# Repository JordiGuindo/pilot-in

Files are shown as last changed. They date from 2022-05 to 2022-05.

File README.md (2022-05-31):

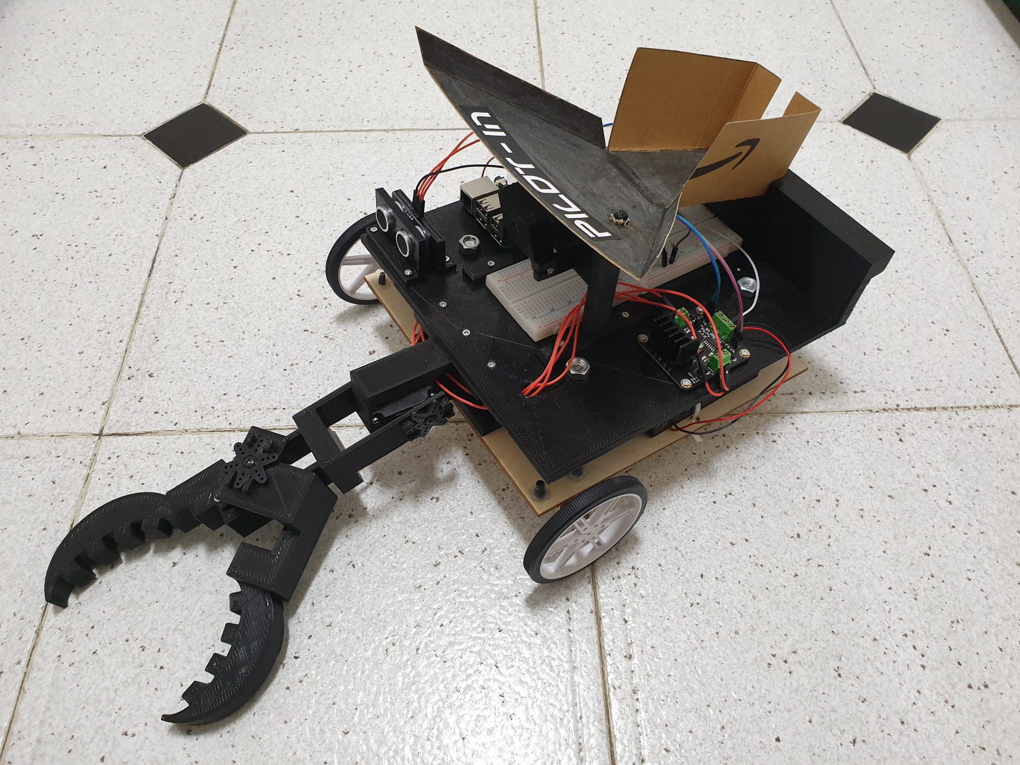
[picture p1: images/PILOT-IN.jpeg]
header pic


# PILOT-IN
This robot recognises ping-pong balls using computer vision and gets them with the help of an arm. It stores them in a removable case. 

# Table of Contents
   * [What is this?](#what-is-this)
   * [Requirements](#requirements)
   * [Amazing contributions](#amazing-contributions)
   * [Hardware](#hardware)
   * [Software](#software)
   	 * [Image capture](#image-capture)
   	 * [Distance sensor module](#distance-sensor-module)
   	 * [Ball detecion](#ball-detection)
	 * [Motion planner](#motion-planner)
   	 * [Wheel control](#wheel-control)
	 * [Arm control](#arm-control)
   * [Contribution](#contribution)
   * [Citing](#citing)
   * [Authors](#authors)
   * [Bibliography](#biblio)
# What is this?
This is our final project for the Robotics, Language and Planification (RLP) subject at the Universitat Autonoma de Barcelona (UAB). 
We presented PILOT-IN, a robot whose objective is to recognise ping-pong balls and pick them up. Here bellow, we explain how the robot was built and how we made it work correctly.
# Requirements
- Coding Requirements
	- [Python 3.10.x](https://www.python.org/)
	- [NumPy](https://numpy.org/)
	- [OpenCV](https://opencv.org/)
- Electronic components
	- Raspberry Pi 3B
	- Raspberry Pi Camera V2
	- Motor Dual controller H-Bridge v1.3
	- Standard servomotor 3001 HB (2)
	- HC-SR04 ultrasonic distance sensor
	- Wheels (2) and crazy wheel
	- Pololu micrometal motors 75:1 (2)
- 3D pieces
	- They are all [here](https://github.com/JordiGuindo/pilot-in/tree/main/3D)
# Amazing contributions
Our robot is aimed at professional ping pong athletes. It will be used in the specific situation where the athlete needs to train a certain aspect of the game for which it is necessary to use several balls. Our robot allows the athlete to train without the help of anyone to collect the balls, which improves the efficiency of training and contributes to the improvement of results in the competition.  
The robot is able to make individual workouts much more efficient, without the need to have people picking up balls.
It can also be used if you are not a professional athlete, but the full potential of the robot will not be exploited, as it will not be used as often. However, it can help to prevent back pain, as it will not be necessary to bend down to look for all the balls. It can be used in cases of therapy, if there has been an injury to the arm. If rehabilitation involves throwing a ball, it may be helpful to the patient.  
On the other hand, our robot is scalable. The design can be adapted for different sports, and different capacities (maximum number of balls collected). Depending on the sport played, the different components of the robot can be changed to collect the balls based on what the playing field is like, what the size of the balls is and what the optimal number of balls to be loaded is.  

# Hardware
The following picture shows how all the electronic components are connected. 
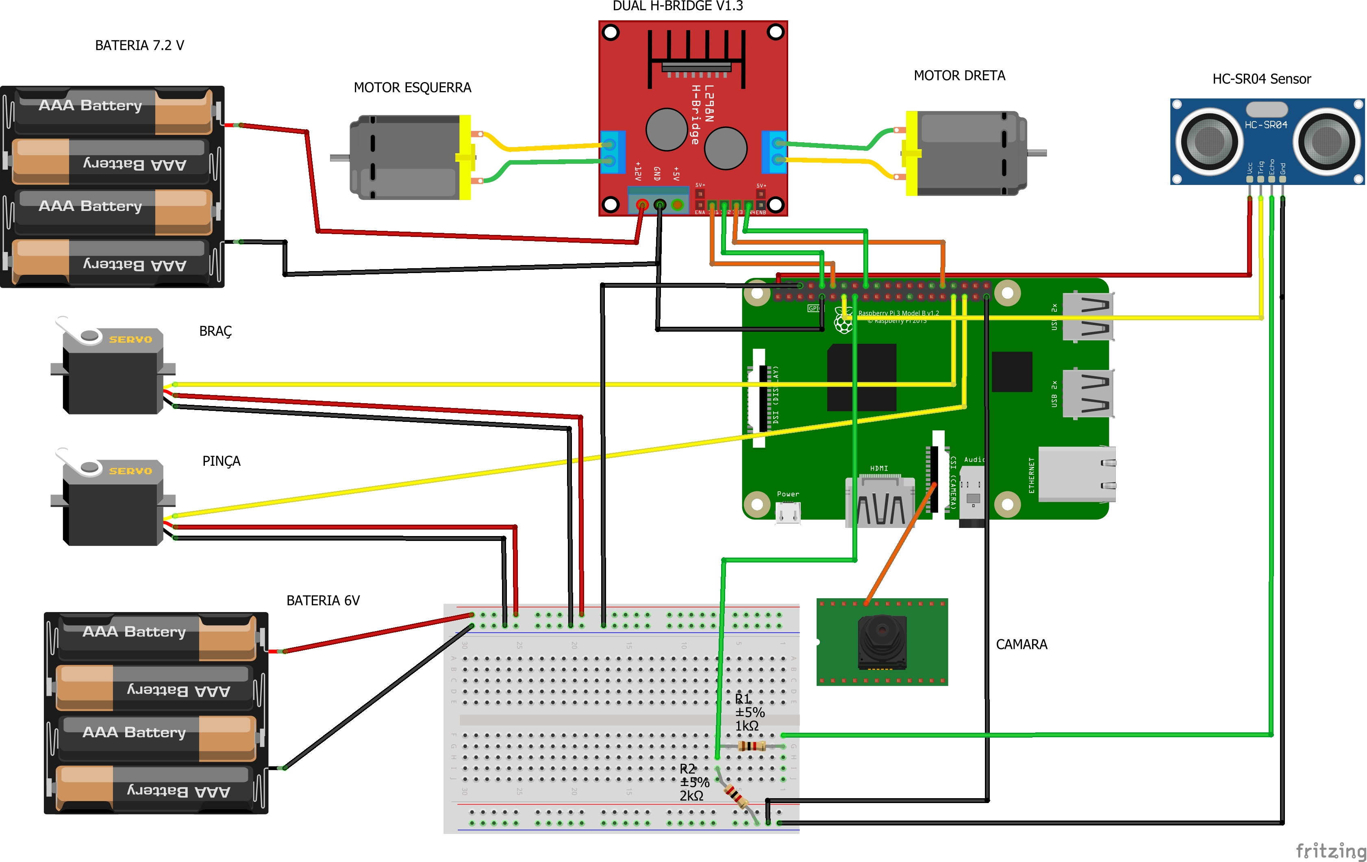
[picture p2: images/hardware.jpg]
  
The Raspberry PI is the brain of PILOT-IN.  
All motors are connected to pins that can give PWM signals, so we can control the amount of power
they recieve. In the case of the wheel motors, we have two cables coming out of the RPi to control each one of them. One controls the speed, the other the direction. 
This connects to the Motor Dual Controller, which will give the corresponding power to the motors. 
With the servomotors only one cable is necessary. Motors are powered by external batteries, 7.2 V for the wheel ones and 6 V for the servomotors.\n
We took advantage of the power supply the RPi can give to power the HC-SR04 ultrasonic sensor. However, a voltage divisor has to be used for the echo pin, 
since the RPi cannot take an input of more than 3.3 V.  
Lastly, we have camera connected to it.    
On the other hand, we used 3D printing to ensemble the full robot. Here is how the final ensemble of this pieces looks like (the black pieces represent the electronic components):
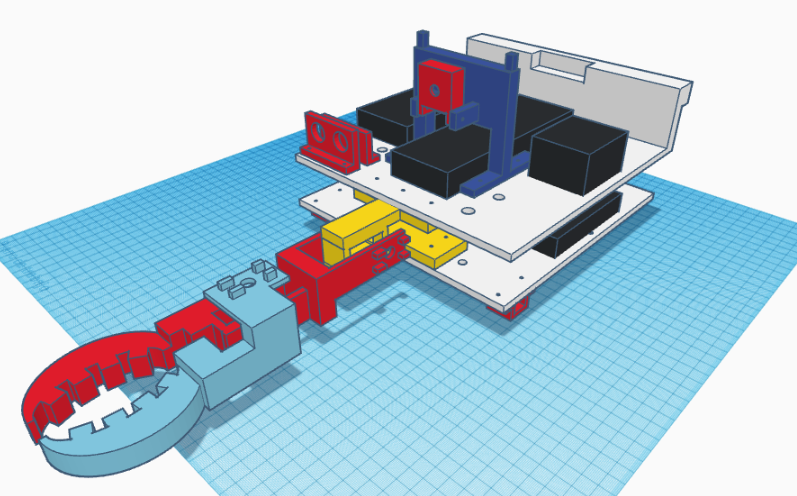
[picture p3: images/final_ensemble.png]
  

# Software
In the following picture are depicted the different software modules. The inputs and outputs of each module can be seen.  
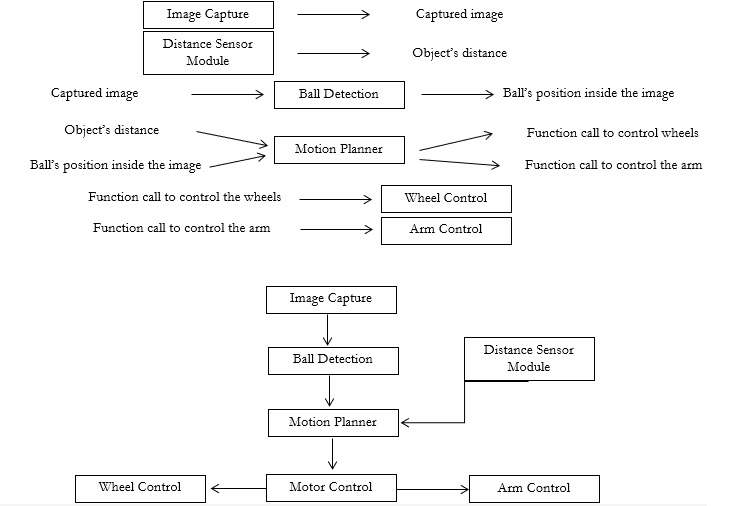
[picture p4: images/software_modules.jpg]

### Image capture
This module takes care of capturing the image that the camera sees. It is implemented directly with the functions that OpenCV provides.
### Distance Sensor Module  
The only library needed for this module is the GPIO library, that allows to control the pins of the RPi. It is entirely in the distance_sensor.py file.
### Ball detection
For this module, the OpenCV library is needed. To detect the balls we use two filters for the image that comes from the Image Capture module: a color filter
and a shape filter. These can be changed. After applying the color filter, a binary image is obtain, where the white pixels represent the color we are looking for.
After that, the shape filter is used to discard other possible objects with the same color. Lastly, we use some OpenCV functions to draw a circle around the ball:  
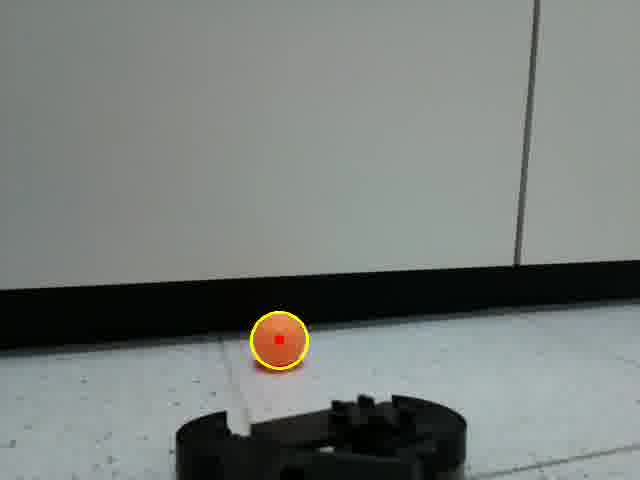
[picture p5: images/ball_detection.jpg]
  
This module is coded in the ball_detection.py file. 
### Motion planner
This is the main module. Depending on what this module recieves from the previous ones, it tells the motors to behave in different ways in order to approach the ball
and get it. It has two modes: the searching mode and the target mode. 
- Searching mode: if a ball is not detected in the ball detection module, the robot will try to find one in the room. This mode uses the ultrasonic distance sensor
to avoid big obstacles, like walls or table legs. PILOT-IN will alternate between moving forward and turning around itself while looking for the ball.
- Target mode: when a ball is detected in the ball detection module, the robot will approach it until it is placed in a reachable position for the arm. Depending on the 
position of the ball, the robot will go forward or will turn left or right. When the ball is in a reachable position, a function is called so the arm moves to pick it up. 
In the following gif, you can see the what the robot sees and how it approaches the ball:
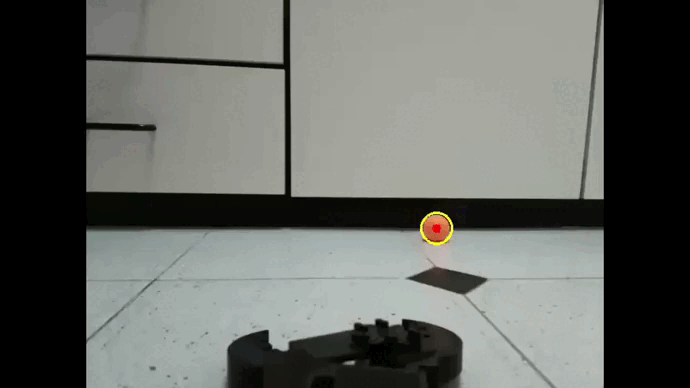
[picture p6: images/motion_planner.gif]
  
This module is coded in the main.py file.

### Wheel control  
This module focuses on doing the control part of the wheels by by using Raspberry PI's signals. Therefore, we use this signals to operate and control the DC motors calling some functions that manage these signals. 
The GPIO library is used for that. All of it is coded in the motor_control.py file.

### Arm control  
This module has the same function as the Wheel Control module, but this module focuses on the arm control. It uses functions and the signals of the Raspberry PI to control the movement of the arm, needed to move the balls into the tube/box.
The GPIO library is also used here. It is coded in the arm_control.py file. 

# Contribution
Feel free to contribute with anything that could potentially improve the project, whether it be design, software architecture, code, hardware components.... Anything is welcomed, and we appreciate contributions.
If you feel like it, feel free to contact the owner of this GitHub. 

# Citing
If you use this project of academic work or industry, please cite it. 
Use this format:   
"PILOT-IN, a robot that uses computer vision to detect and pickup sport balls", 2022, name of the authors (our names), link to this GitHub.

# Authors
Sergi Sánchez Hernández  
Francisco A. Molina Bakhos  
Jordi Guindo Martínez  
Ferran Anton Serrano  

# Bibliography
This project has been inspired by the following Internet projects:  
"Robot recogepelotas", MECATRONICA ESPE LATACUNA ECUADOR - SUDAMÉRICA, https://www.youtube.com/watch?v=108TMEKc74c  
“Sistema autónomo para recolección de bolas de tenis mediante vision artificial”, D. Gaitán Tabares, H. Martínez Arcila. Universidad Distrital Francisco José Caldas, 2015.  
Here you can find what we have used to code the robot:  
"Teach, Learn, and Make with Raspberry PI", https://www.raspberrypi.org/  
"RPi.GPIO - PyPI", https://pypi.org/project/RPi.GPIO/  
"OpenCV", https://opencv.org/

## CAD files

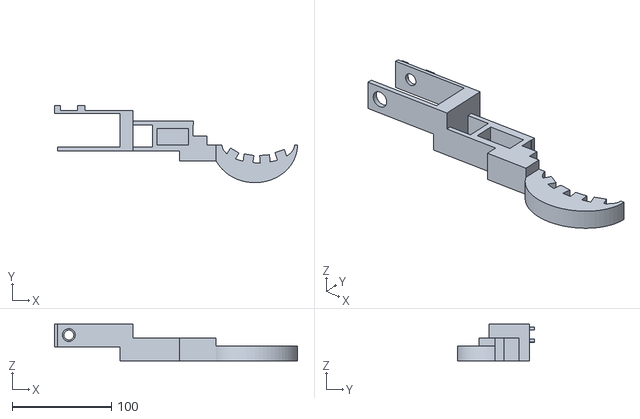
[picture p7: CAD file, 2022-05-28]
3D/PILOT-IN ARM.stl
245.0 x 78.0 x 37.0

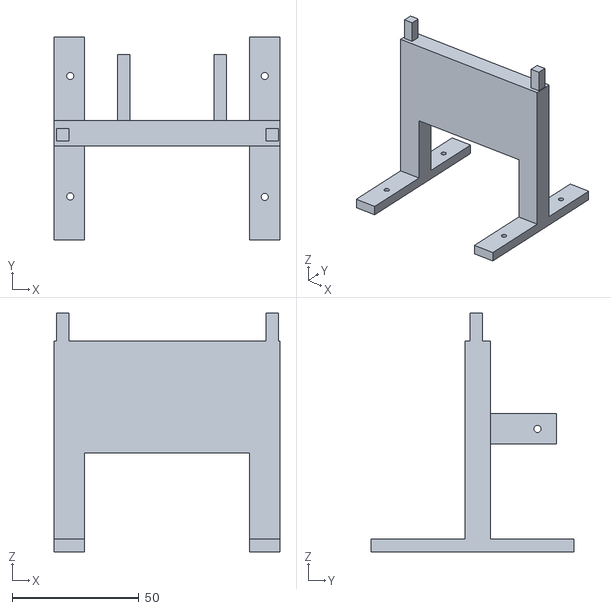
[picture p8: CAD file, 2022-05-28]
3D/PILOT-IN CAMERA+TUBE SUPPORT.stl
89.0 x 80.0 x 94.0

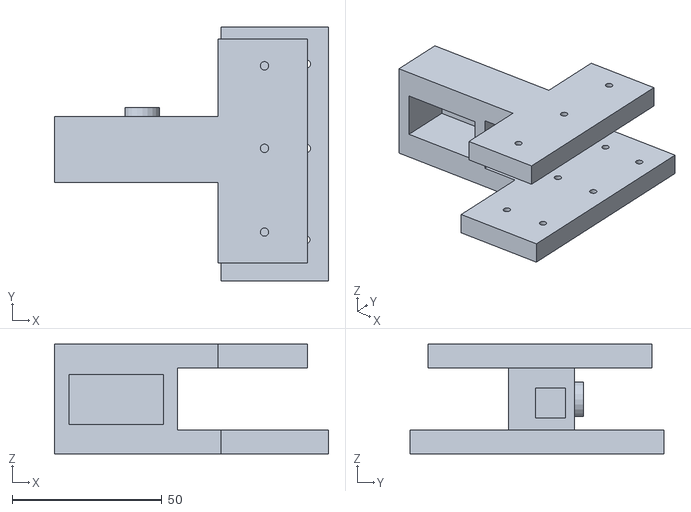
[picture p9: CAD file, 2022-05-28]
3D/PILOT-IN ARM SUPPORT.stl
91.6 x 85.0 x 36.8

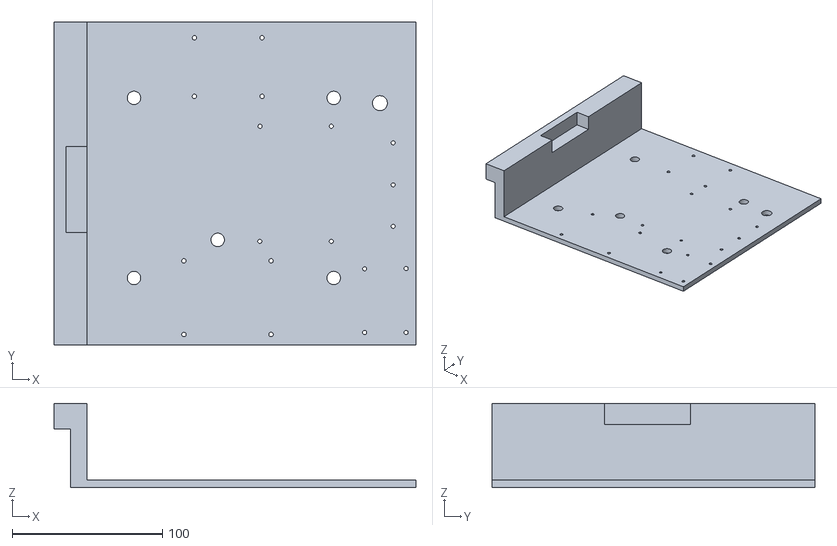
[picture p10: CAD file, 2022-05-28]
3D/PILOT-IN BODY UP.stl
241.0 x 215.0 x 56.0

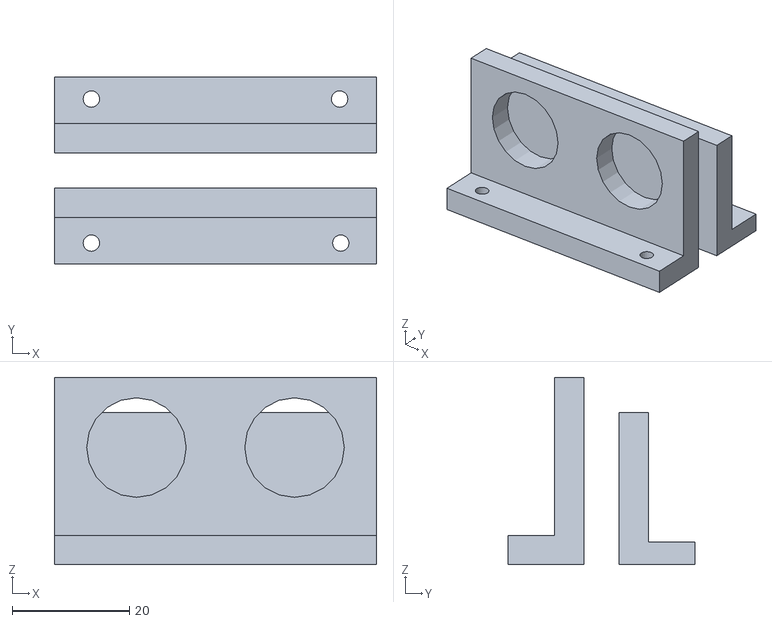
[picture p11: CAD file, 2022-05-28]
3D/PILOT-IN HC-SR04 CASE.stl
55.0 x 32.0 x 32.0

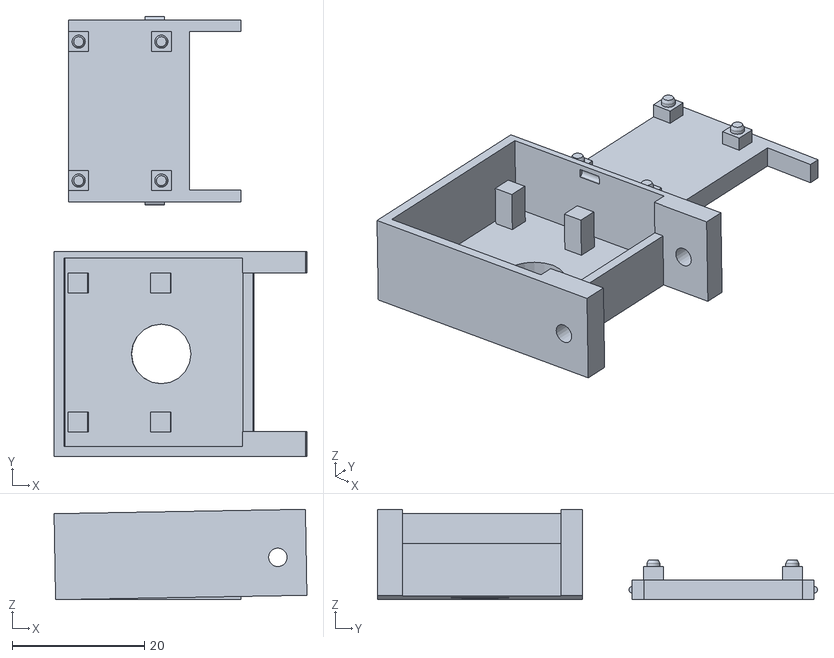
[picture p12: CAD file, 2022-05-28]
3D/Raspberry Camera Case.stl
38.2 x 66.5 x 13.7

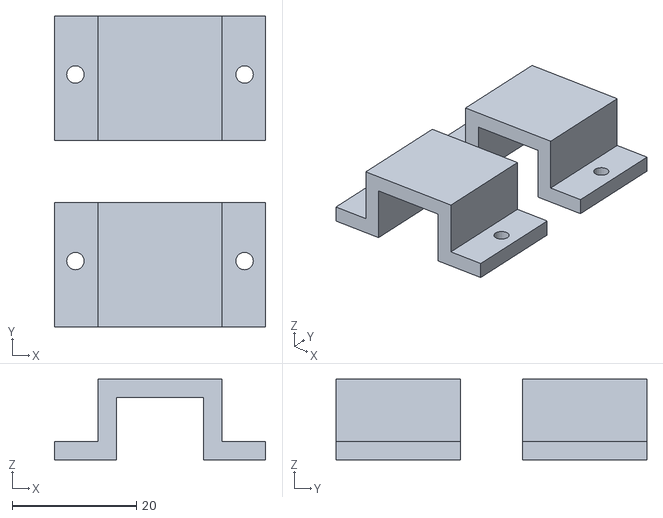
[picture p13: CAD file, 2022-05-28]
3D/MICROMETAL MOTOR CLAMP.stl
34.0 x 50.0 x 13.0

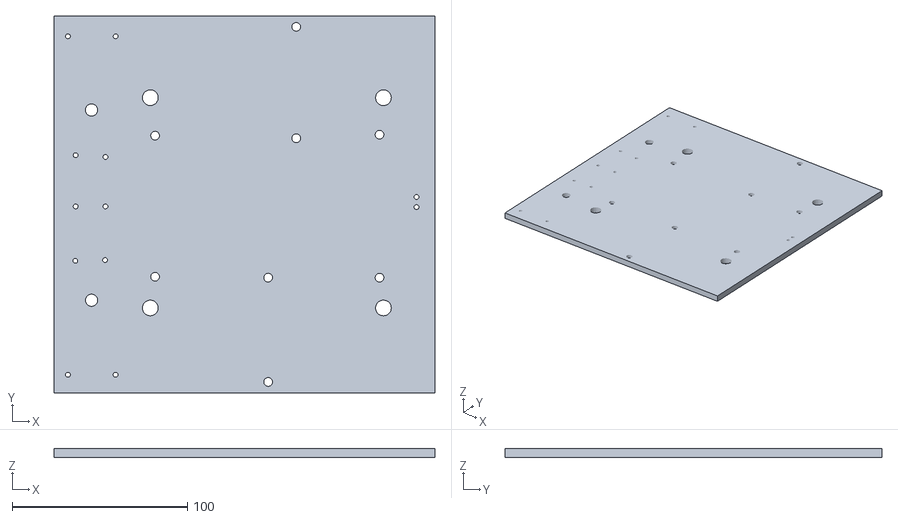
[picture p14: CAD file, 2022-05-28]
3D/PILOT-IN BODY DOWN.stl
217.0 x 215.0 x 5.00

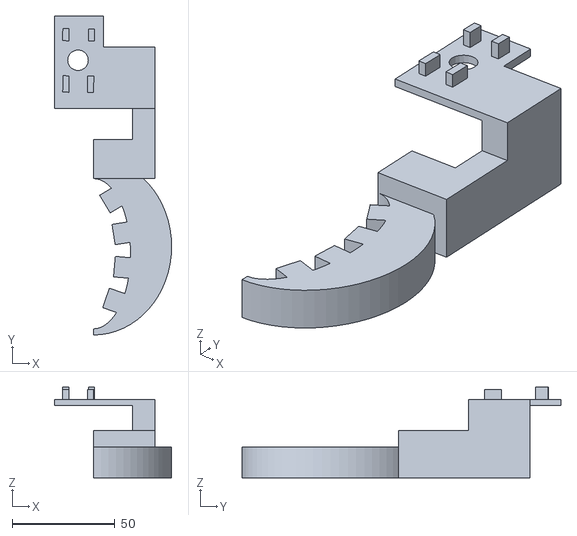
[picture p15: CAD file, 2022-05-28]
3D/PILOT-IN WRIST.stl
57.0 x 155.0 x 44.0

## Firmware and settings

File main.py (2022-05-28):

import cv2
import ball_detection as bd
import motor_control as mc
import numpy as np
import RPi.GPIO as GPIO
import time
import arm_control as ac
import distance_sensor as ds


if __name__ == "__main__":
    # First, we initialize all of the pins
    
    # This pins control the wheel motors (e for speed, m for direction)
    e1 = 12
    m1 = 10
    e2 = 32
    m2 = 18

    GPIO.setmode(GPIO.BOARD)
    GPIO.setup(e1, GPIO.OUT)
    GPIO.setup(m1, GPIO.OUT)
    GPIO.setup(e2, GPIO.OUT)
    GPIO.setup(m2, GPIO.OUT)

    pwm_1 = GPIO.PWM(e1, 500)
    pwm_2 = GPIO.PWM(e2, 500)
    
    # This two pins control the arm and the wrist
    wristPin=35
    armPin =33
    GPIO.setup(wristPin,GPIO.OUT)
    GPIO.setup(armPin, GPIO.OUT)
    pwm_w=GPIO.PWM(wristPin, 100)
    pwm_a = GPIO.PWM(armPin, 100)

    pwm_1.start(0)
    pwm_2.start(0)
    vs = cv2.VideoCapture(0)
    pwm_w.start(0)
    pwm_a.start(0)
    
    # This two pins control de distance sensor
    trigger = 13
    echo = 15
     
    #set GPIO direction (IN / OUT)
    GPIO.setup(trigger, GPIO.OUT)
    GPIO.setup(echo, GPIO.IN)
    
    
    # This variable is used to ensure the ball is in a correct position
    # for some iterations to pick it up
    counter_ball = 0
    
    # These variables are used to make the robot search for balls in different locations
    # If searching is False, the robot will be rotating. If it is True, it will be going forward.
    # We will also use it to make use of the distance sensor when going forward,
    # to avoid crashing
    searching = False
    # Counter_distance will be used for counting iterations. If the distance is close during
    # several iterations, the robot will stop and will rotate
    counter_distance = 0
    # Timer will help with changing the variable searching. If the robot does not find a ball
    # it will be rotating for 20 s and going forward for 3 s in a loop, unless the distance
    # sensor says otherwise
    t = 20
    t0 = time.time()
    

    while True:
        # We get the current frame
        ret, frame = vs.read()
        if frame is None:
            break
        x, y, r = bd.detect_ball(frame)
        # We show the frame with the ball detected (if there is one)
        cv2.imshow("Frame", frame)
        key = cv2.waitKey(1) & 0xFF
        if x != -1:
            t0 = time.time()
        
        # This part of the code controls when the robot has to change between
        # rotating and going forward if the ball is not found
        t1 = time.time() - t0
        if t1 > t and x == -1:
            if not searching:
                # If the robot has to go forward, we ensure that there is not an obstacle in front
                # of it at least in a distance of 1 m
                pwm_1.ChangeDutyCycle(0)
                pwm_2.ChangeDutyCycle(0)
                time.sleep(0.2)
                d1 = ds.distance(trigger, echo)
                time.sleep(0.1)
                d2 = ds.distance(trigger, echo)
                time.sleep(0.1)
                if d1 > 60 and d2 > 60:
                    print("There is not an in front object. Going forward")
                    t = 15
                    searching = True
                    t0 = time.time()
                else:
                    # If there is an obstacle, we keep rotating for 5 more seconds
                    print("There is an obstacle. Keep rotating")
                    t0 = time.time() - 15
            else:
                print("Let's look for a ball in this position")
                t = 20
                searching = False
                t0 = time.time()
            
        # This function tells the wheel motors how to move with the purpose of centering the ball
        # so the robot can take it. It also tells them how to move if there is not a ball
        c = mc.center_ball(x, pwm_1, pwm_2, m1, m2, searching)
        
        if searching and x == -1:
            d = ds.distance(trigger, echo)
            time.sleep(0.07)
            if d < 70:
                counter_distance += 1
            if counter_distance > 5:
                print("Object too close. Start rotating")
                t = 20
                searching = False
                t0 = time.time()
                counter_distance = 0
                
        
        
        # If the ball is in a position where the arm can take it,
        # we wait for a few iterations until we are sure that is the case
        if x > 240 and x < 360 and y > 400:
            counter_ball += 1
            pwm_1.ChangeDutyCycle(0)
            pwm_2.ChangeDutyCycle(0)
            print("Preparing to get_ball...")
        elif (c == 1):
            counter_ball = 0
            mc.go_forward(pwm_1, pwm_2, m1, m2, y)
            
        # If the ball has been on a reachable position for 20 iterations,
        # we pick it up
        if counter_ball == 20:
            ac.get_ball(pwm_w, pwm_a)
            print("Ball taken")
            
            
        if key == ord("q"):
            break
    
        
    pwm_1.stop()
    pwm_2.stop()
    pwm_w.stop()
    pwm_a.stop()
    GPIO.cleanup()
    vs.release()
    cv2.destroyAllWindows()

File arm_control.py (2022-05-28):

import RPi.GPIO as GPIO
import time

# Function to go from angle to PWM signal
def AngleToDuty(ang):
  return float(ang)/10.+5.
  
#Setup servoPin as PWM output of frequancy 100Hz

def get_ball(pwm_w, pwm_a):
    # This function makes the arm get the ball once it is in position
    print("Getting ball")
    # First, we close the wrist
    pwm_w.ChangeDutyCycle(AngleToDuty(170))
    time.sleep(5)
    pwm_w.ChangeDutyCycle(AngleToDuty(140))
    time.sleep(0.2)
    pwm_w.ChangeDutyCycle(AngleToDuty(135))
    time.sleep(0.2)
    pwm_w.ChangeDutyCycle(AngleToDuty(130))
    time.sleep(0.2)
    pwm_w.ChangeDutyCycle(AngleToDuty(125))


    # Then, we elevate the arm to put the ball in the tube
    for i in range(170, 50, -2):
        pwm_a.ChangeDutyCycle(AngleToDuty(i))
        time.sleep(0.1)

    # We open the wrist
    pwm_w.ChangeDutyCycle(AngleToDuty(140))
    time.sleep(0.2)

    # We put down the arm
    for i in range(50, 176, 2):
        pwm_a.ChangeDutyCycle(AngleToDuty(i))
        time.sleep(0.1)

    # We open the wrist fully again to get the next ball
    pwm_w.ChangeDutyCycle(AngleToDuty(170))
    time.sleep(0.2)

    time.sleep(1)
    pwm_w.ChangeDutyCycle(0)
    pwm_a.ChangeDutyCycle(0)

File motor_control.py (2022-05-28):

import RPi.GPIO as GPIO
import time

# Constants to control the position where we want the ball to be in the image to pick it up
half = 320
full = 640
half_right = half + 20
half_left = half - 40
range_f = 300

def center_ball(x, pwm_1, pwm_2, m1, m2, searching):
    # This function tells the motors how to move taking into account the x position of the ball
    # in the image

    # If there is no ball and we are not going forward, the motors rotate the robot
    if x == -1 and not searching:
        GPIO.output(m1, True)
        GPIO.output(m2, False)
        print("Ball not detected. Looking for ball. Rotating")
        pwm_1.ChangeDutyCycle(int(65))
        pwm_2.ChangeDutyCycle(int(65))
        return -1
    # If there is no ball and we are going forward, the motors move the robot forward
    if x == -1 and searching:
        GPIO.output(m1, False)
        GPIO.output(m2, False)
        print("Ball not detected. Looking for ball. Going forward")
        pwm_1.ChangeDutyCycle(int(47))
        pwm_2.ChangeDutyCycle(int(47))
        return -1
    # If there is a ball, and it is already centered in the image, we will go forward
    if x > half_left and x < half_right:
        print("On center")
        return 1
    # If there is a ball on the right of the screen, the robot turns right
    elif x > half_right:
        GPIO.output(m1, False)
        GPIO.output(m2, True)
        speed = int((x/range_f - 1)*15 + 50)
        print("Turning right")
        pwm_1.ChangeDutyCycle(int(55))
        pwm_2.ChangeDutyCycle(int(55))
    # If there is a ball on the left of the screen, the robot turns left
    elif x < half_left:
        GPIO.output(m1, True)
        GPIO.output(m2, False)
        print("Turning left")
        pwm_1.ChangeDutyCycle(int(60))
        pwm_2.ChangeDutyCycle(int(60))
        
    return 0

def go_forward(pwm_1, pwm_2, m1, m2, y):
    # This function makes the robot go forward when the ball is already centered. 
    GPIO.output(m1, False)
    GPIO.output(m2, False)
    if y > 300:
        speed = 45
    else:
        speed = 50
    pwm_1.ChangeDutyCycle(speed)
    pwm_2.ChangeDutyCycle(speed)
    print("Going forward")

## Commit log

2022-04-24 Código básico añadido
    Los archivos subidos hacen poca cosa: ball_detection detecta las pelotas de ping pong naranjas, arm_control mueve un servomotor de un lado a otro 4 veces, y motor_control hace que un motor vaya hacia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
2022-04-27 Código ball_detection + motor_control
2022-05-11 Arm control added + main and motor_control modifications
2022-05-14 Integration of arm_control and motor_control on main
2022-05-20 Distance sensor added + updated files
2022-05-21 Distance sensor integrated + modifications motor control
2022-05-28 GitHub presentation
    [MICROMETAL MOTOR CLAMP.stl, PILOT-IN ARM SUPPORT.stl, PILOT-IN ARM.stl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]
